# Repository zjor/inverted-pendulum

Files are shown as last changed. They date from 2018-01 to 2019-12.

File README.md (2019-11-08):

# Inverted Pendulum 

This repo contains simulations and numerical experiments related to my inverted pendulum robot hobby project

## Working project video

Inverted pendulum (https://www.youtube.com/watch?v=nOSTzpA0nGk)

## Articles
- [Все, что вы хотели знать об обратном маятнике](https://habr.com/ru/post/472588/)

## References
1. [Swing-up algorithm](https://pdfs.semanticscholar.org/47ef/ea6c73ef96ae933a378d4bf7ff3245a8584d.pdf)

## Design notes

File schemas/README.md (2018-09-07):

# Dimentions
For 2040 v-slot beam the distance between 23.89mm wheel centers is 60.4mm

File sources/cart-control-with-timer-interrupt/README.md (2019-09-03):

# Cart position control with timer interrupt

This code controls position of a cart with a stepper motor. Timer interrupt is used to control step delay precisely.

## Hardware
- DQ542MA stepper driver
- Arduino Uno
- Nema 17 stepper motor: 17HS4401

## Thoughts

Usage of interrupts allows logging system's state to console.
The problem arises when the motor should be driven very slowly, velocity update happens each step, e.i. each ISR call and if there is enough time between calls the system will evolve before the change is recognised and reflected in motion.

## References
- (http://maxembedded.com/2011/07/avr-timers-ctc-mode/)
- (https://www.instructables.com/id/Arduino-Timer-Interrupts/)

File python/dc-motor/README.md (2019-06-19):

# DC-motor simulations

## Equations of motion

### Electrical equation

U = L\frac{di}{dt} + Ri + kw

where 
- U - input voltage
- L - rotor inductance
- R - rotor coils resistance
- kw - back EMF term proportional to w

### Mechanical equation

J\frac{dw}{dt} + Bw = T_M - T_L = ki - mr^2\frac{dw}{dt}

where
- J - momentum of inertia of the rotor
- B - friction due to rotation
- T<sub>M</sub> - torque of the motor
- T<sub>L</sub> - torque of the load
- m - mass of the load
- r - radius of the shaft

Note that the friction due to the movement of the mass is neglected.

### Assumptions

\frac{L}{R} << \frac{J}{B}, => i = \frac{U}{R} - \frac{k}{Rw}

thus the DC-motor can be described with one equation

\frac{dw}{dt}(J + mr^2) + w(B + \frac{k^2}{R}) = \frac{kU}{R}

## The system to control

In this example I want to position a cart pulled by the motor at certain location, so that the system transitions from the state [x1, w1 (typically w1 = 0)] to [0, 0]

### Equations of the system

\begin{cases}\dot{x} = wr\\\dot{w}=-\alpha w + \beta U\end{cases}

where

\alpha = \frac{B + k^2/R}{J + mr^2} and 
\beta = \frac{k}{R(J + mr^2)}

### Controllability

A=\begin{bmatrix}0 & r\\ 0 & -\alpha\end{bmatrix}

B=\begin{bmatrix}0\\ \beta\end{bmatrix}

Controllability matrix 
\begin{bmatrix}B && AB\end{bmatrix} = \begin{bmatrix}0 && r\beta\\\beta && -\alpha\beta\end{bmatrix}
, rank equals 2 thus the system is controllable

## Step response
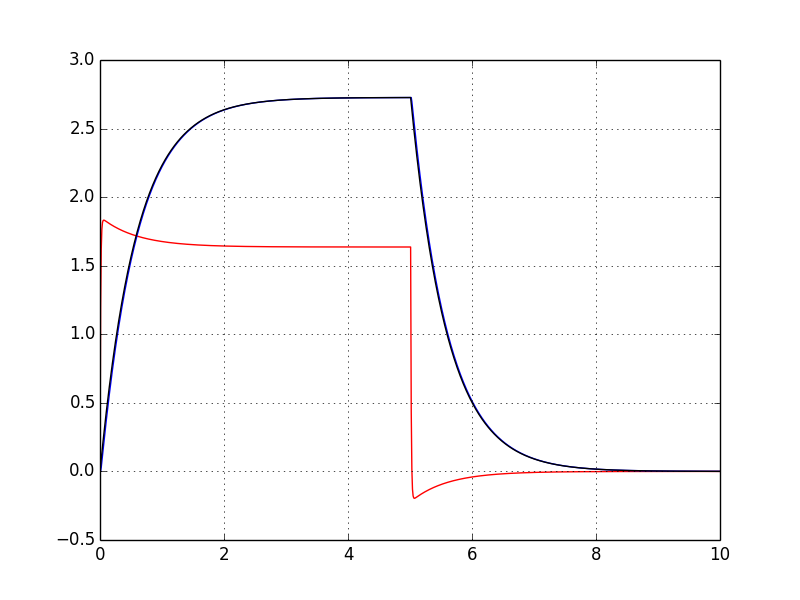
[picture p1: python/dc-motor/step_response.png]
Step Response


## PID controller
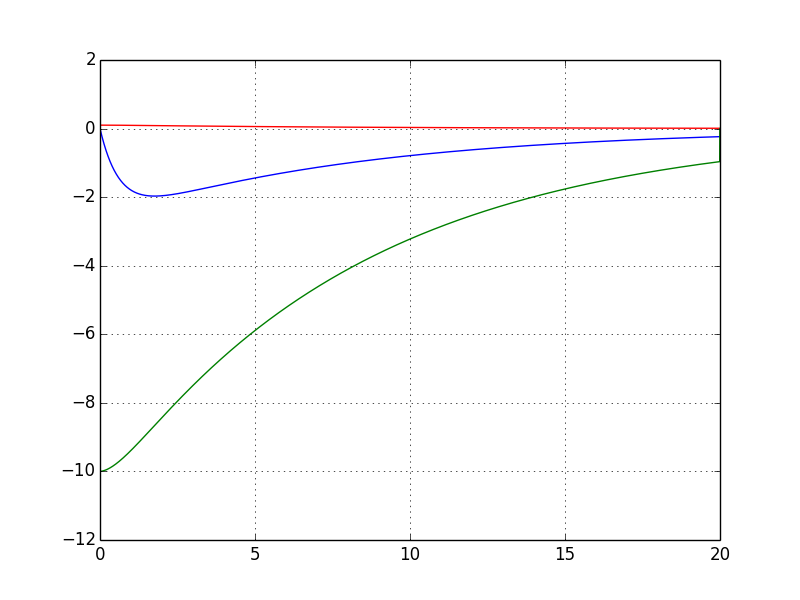
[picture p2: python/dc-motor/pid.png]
PID results


## LQR controller
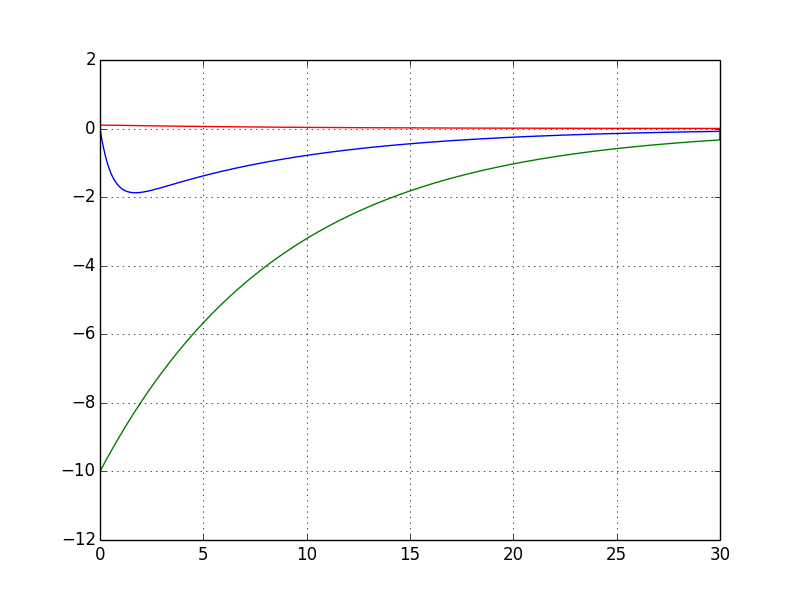
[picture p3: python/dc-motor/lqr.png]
LQR results


## TODO

- find alpha, beta parameters for the real motor based in step response
- take into account load friction and stall torque

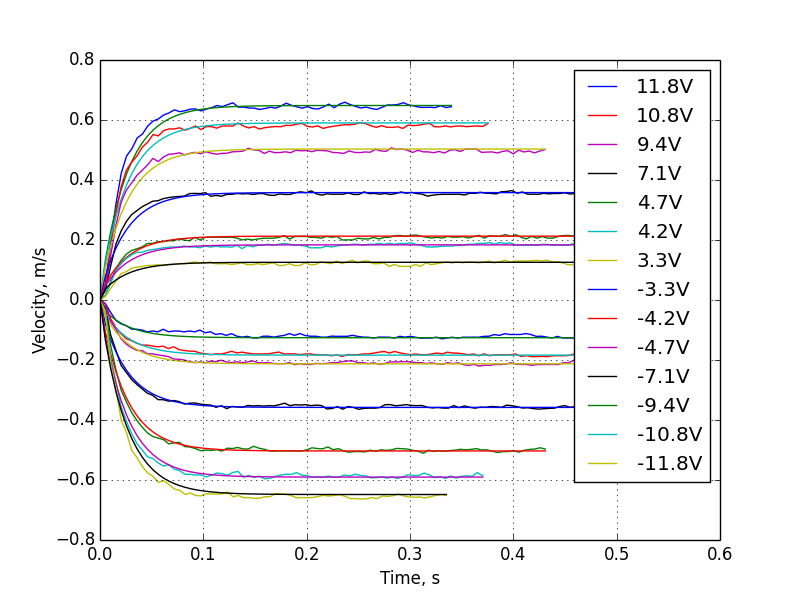
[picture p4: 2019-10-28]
dc-motor/params_fit.png

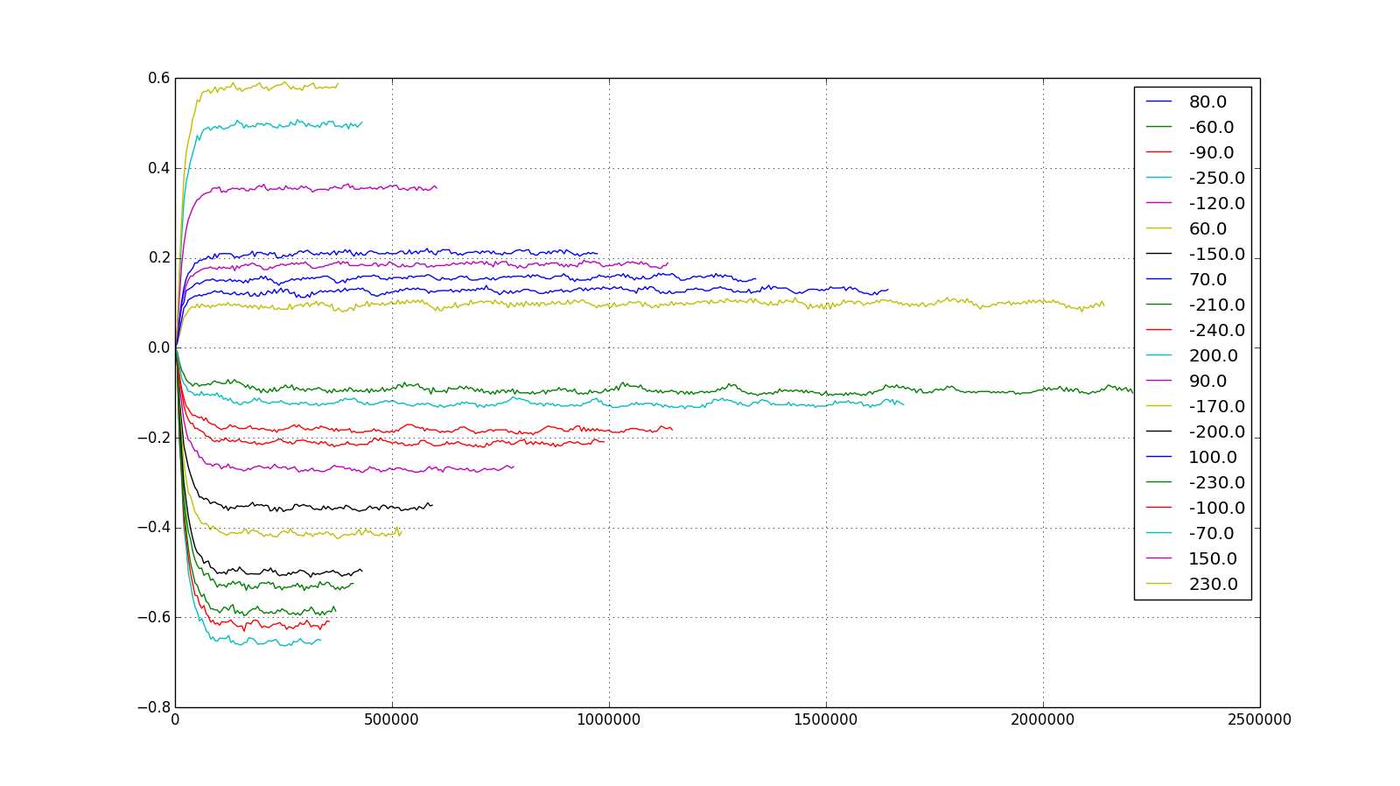
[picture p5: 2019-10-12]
dc-motor/velocity_per_pwm.png

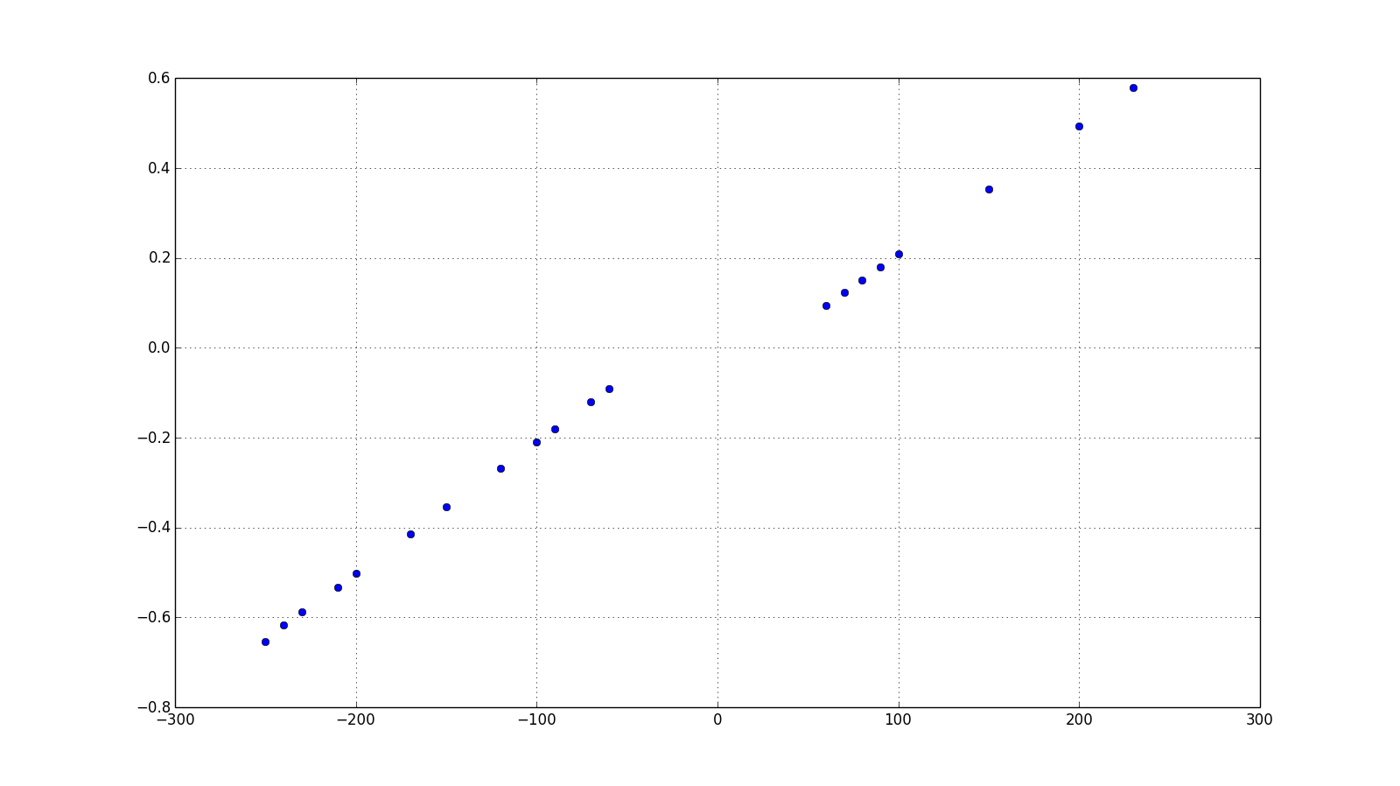
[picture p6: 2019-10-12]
dc-motor/set_velocity_per_pwm.png

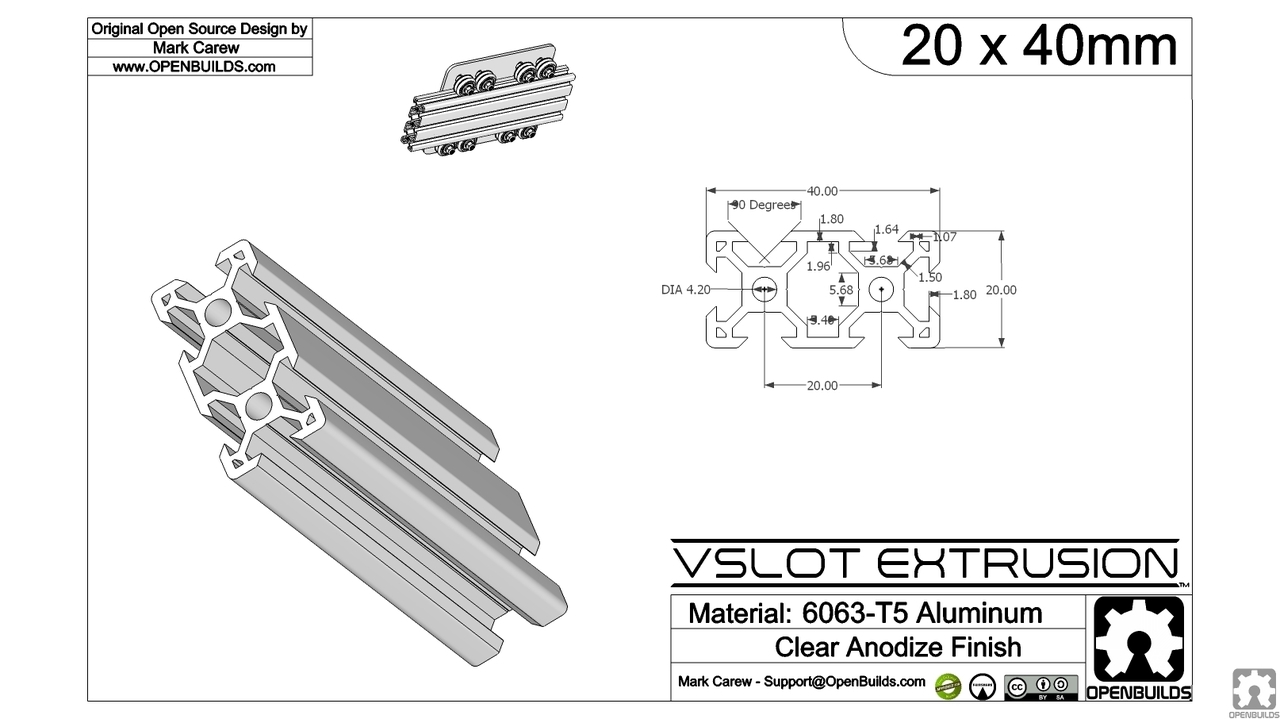
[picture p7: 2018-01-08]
schemas/v-slot_20x40.jpg

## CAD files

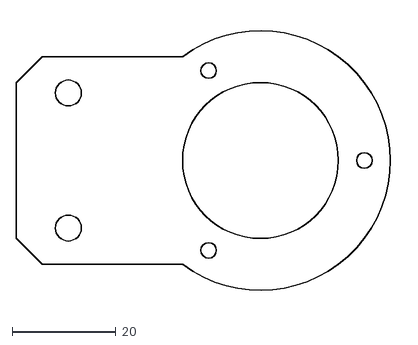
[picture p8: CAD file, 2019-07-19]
schemas/v2/encoder-holder.dxf
74.2 x 55.5

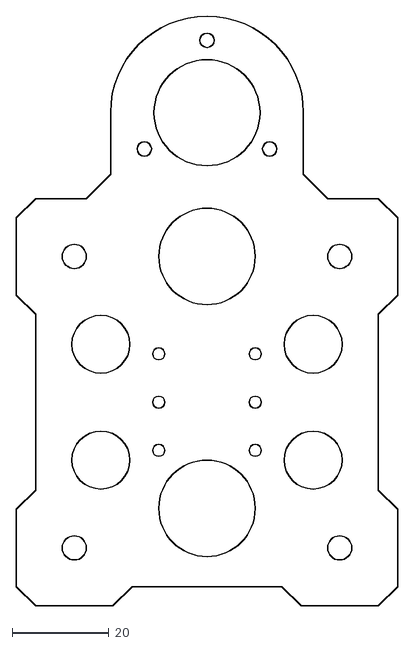
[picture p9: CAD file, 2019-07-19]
schemas/v2/cart-front.dxf
79.1 x 122.2

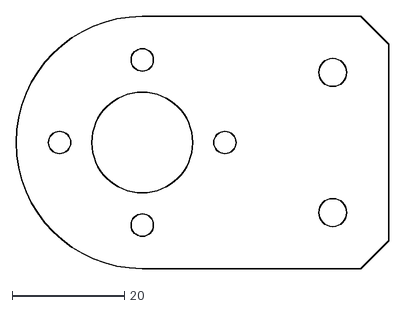
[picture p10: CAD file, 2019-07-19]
schemas/v2/motor-holder.dxf
66.5 x 45.0

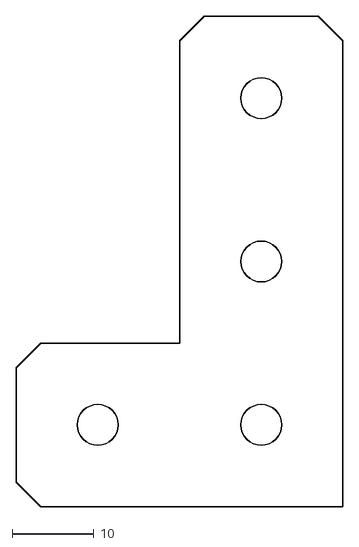
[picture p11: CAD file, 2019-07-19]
schemas/v2/beam-connector.dxf
40.0 x 60.0

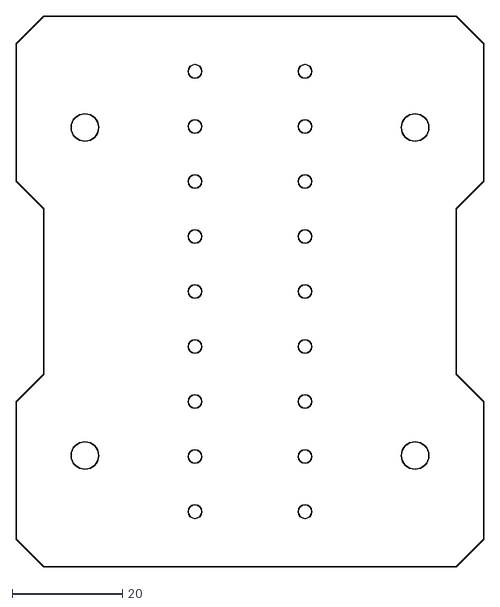
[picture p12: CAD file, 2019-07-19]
schemas/v2/cart-top.dxf
85.0 x 100.0

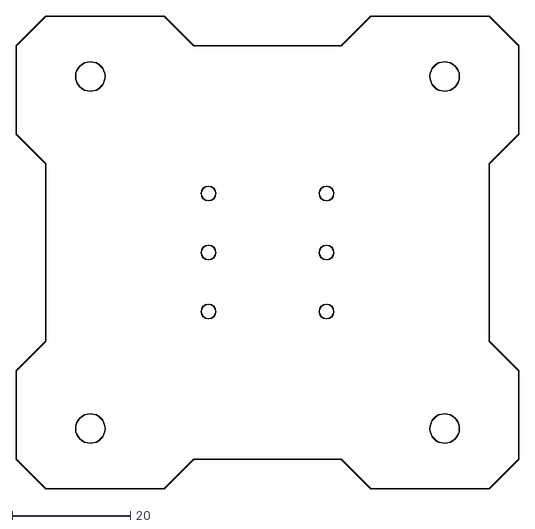
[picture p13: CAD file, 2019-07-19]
schemas/v2/cart-bottom.dxf
85.0 x 80.0

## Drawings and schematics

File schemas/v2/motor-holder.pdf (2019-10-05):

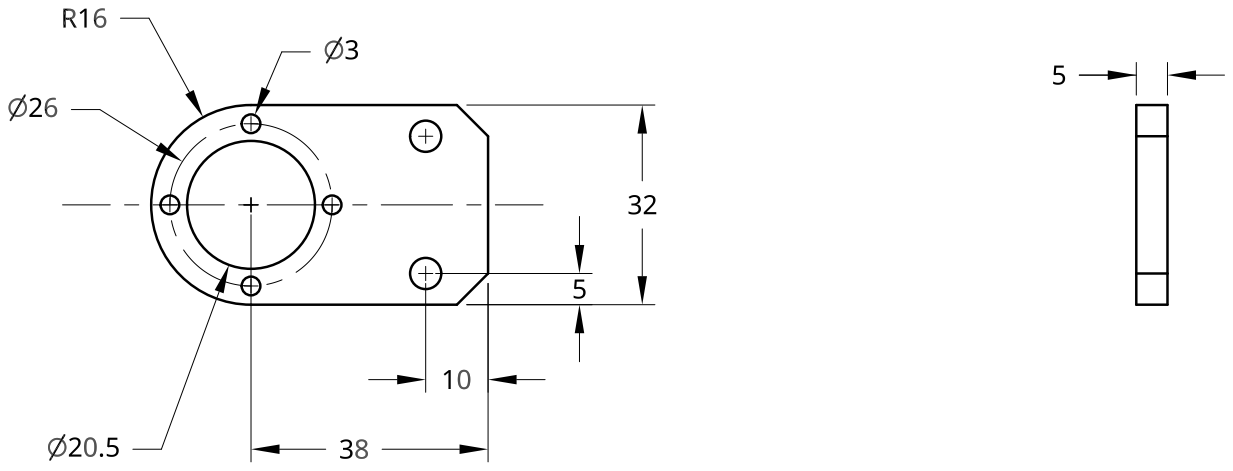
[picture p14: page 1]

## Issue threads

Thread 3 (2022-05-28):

estimate_params.py

yunjs24, 2022-05-28:
## inverted-pendulum/dc-motor/estimate_params.py ,  line 33

    when map obj converted into numpy array, it cannot express column size in data.shape

   so line 33
    with open(filename) as f:
        reader = csv.reader(f)
        for row in reader:
            data.append(map_to_float(row)) >> data.append(list(map(float, row)))

  tested in
  OS : wsl2 ubuntu in windows10
  pip 20.0.2 (python 3.8)

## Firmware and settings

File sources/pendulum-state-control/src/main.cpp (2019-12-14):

/**
 * == Inverted pendulum stabilisation with state control with DC motor ==
 * 
 * == Hardware specification ==
 * OMRON E6B2-CWZ6C pinout
 * - Brown - Vcc
 * - Black - Phase A
 * - White - Phase B
 * - Orange - Phaze Z
 * - Blue - GND
 *
 * LPD3806-600BM-G5-24C pinout
 * - Green - Phase A
 * - White - Phase B
 * - Red - Vcc
 * - Black - GND
 */

#include <Arduino.h>

// motor encoder pins
#define OUTPUT_A  3 // PE5
#define OUTPUT_B  2 // PE4

// pendulum encoder pins
#define REF_OUT_A 18 // PD3
#define REF_OUT_B 19 // PD2

// terminal switches pins
#define SWITCH_RIGHT  21
#define SWITCH_LEFT  20

// pulses per revolution
#define PPR  2400
#define SHAFT_R 0.00573
#define PENDULUM_ENCODER_PPR  10000

#define PWM_PIN 10
#define DIR_PIN 8

#define POSITION_LIMIT  0.145

#define STATE_CALIBRATE 0
#define STATE_SWING_UP  1
#define STATE_BALANCE   2
#define STATE_FULL_STOP 3
#define STATE_GO_RIGHT  4 
#define STATE_GO_LEFT   5
#define STATE_GO_CENTER 6

#define A 35.98
#define B 2.22
#define C 2.79

#define Kth 147.1
#define Kw  36.0
#define Kx  54.0
#define Kv  39.5

const float THETA_THRESHOLD = PI / 12;
const float PI2 = 2.0 * PI;

volatile long encoderValue = 0L;
volatile long lastEncoded = 0L;

volatile long refEncoderValue = 0;
volatile long lastRefEncoded = 0;

volatile boolean leftSwitchPressed = false;
volatile boolean rightSwitchPressed = false;

unsigned long now = 0L;
unsigned long lastTimeMicros = 0L;

// pulses count before the right switch pressed
long rightSwitchPulses;

float x, last_x, v, dt;
float theta, last_theta, w;
float control, u;

unsigned long log_prescaler = 0;

volatile bool debounce = false;
volatile long debounceTimestampMillis;

int state;

void encoderHandler();
void refEncoderHandler();

void leftSwitchHandler();
void rightSwitchHandler();

void calibrate();

void setup() {

  // setting PWD frequency on pin 10 to 31kHz
  TCCR2B = (TCCR2B & 0b11111000) | 0x01;

  pinMode(OUTPUT_A, INPUT_PULLUP);
  pinMode(OUTPUT_B, INPUT_PULLUP);

  pinMode(REF_OUT_A, INPUT_PULLUP);
  pinMode(REF_OUT_B, INPUT_PULLUP);

  pinMode(SWITCH_LEFT, INPUT);
  pinMode(SWITCH_RIGHT, INPUT);

  attachInterrupt(digitalPinToInterrupt(OUTPUT_A), encoderHandler, CHANGE);
  attachInterrupt(digitalPinToInterrupt(OUTPUT_B), encoderHandler, CHANGE);

  attachInterrupt(digitalPinToInterrupt(REF_OUT_A), refEncoderHandler, CHANGE);
  attachInterrupt(digitalPinToInterrupt(REF_OUT_B), refEncoderHandler, CHANGE);

  attachInterrupt(digitalPinToInterrupt(SWITCH_LEFT), leftSwitchHandler, FALLING);
  attachInterrupt(digitalPinToInterrupt(SWITCH_RIGHT), rightSwitchHandler, FALLING);


  pinMode(PWM_PIN, OUTPUT);
  pinMode(DIR_PIN, OUTPUT);

  digitalWrite(DIR_PIN, LOW);

  Serial.begin(9600);
  lastTimeMicros = 0L;
  state = STATE_CALIBRATE;
}

float saturate(float v, float maxValue) {
  if (fabs(v) > maxValue) {
    return (v > 0) ? maxValue : -maxValue;
  } else {
    return v;
  }
}

float getAngle(long pulses, long ppr) {  
  float angle = (PI + PI2 * pulses / ppr);
  while (angle > PI) {
    angle -= PI2;
  }
  while (angle < -PI) {
    angle += PI2;
  }
  return angle;
}

float getCartDistance(long pulses, long ppr) {
  return 2.0 * PI * pulses / PPR * SHAFT_R;
}

void driveMotor(float u) {
  digitalWrite(DIR_PIN, u > 0.0 ? LOW : HIGH);
  analogWrite(PWM_PIN, fabs(u));
}

boolean isControllable(float theta, float w, float x) {
  return fabs(theta) < THETA_THRESHOLD && fabs(w) < 0.5 && fabs(x) < 0.05;
}

void log_state(float control, float u) {
  if (fabs(w) > 100) {
    return;
  }

  if (state == STATE_FULL_STOP) {
    return;
  }

  // if (log_prescaler % 5 == 0) {
    Serial.print(state);Serial.print("\t");
    Serial.print(theta, 4);Serial.print("\t");
    Serial.print(w, 4);Serial.print("\t");
    Serial.print(x, 4);Serial.print("\t");
    Serial.print(v, 4);Serial.print("\t");
    Serial.print(control, 4);Serial.print("\t");
    Serial.println(u, 4);
  // }
  log_prescaler++;
}

float getBalancingControl(float x, float v, float theta, float w) {
  return Kx * x + Kv * v + Kth * theta + Kw * w;
}

float getSwingUpControl(float x, float v, float theta, float w) {
  float K = 10.0;
  float c = -copysignf(K, - w * cos(theta));
  float lim = 0.01;
  if ((x >= lim && c > 0) || (x <= -lim && c < 0) || fabs(theta) < PI / 2) {
    c = -(A * v + copysignf(C, v)); // causes to stop immediately
  }
  return c;
}

float integralError = 0.0;
float lastTarget = 0.0;
float getVelocityControl(float v, float target, float dt) {

  if (lastTarget != target) {
    lastTarget = target;
    integralError = 0.0;
  }

  float error = target - v;
  float Kp = 50.0;
  float Ki = 10.0;
  integralError += Ki * error * dt;
  return Kp * error + integralError;
}

float getPositionControl(float x, float v, float target) {
  float pKx = 60.0; //285.4;
  float pKv = 5.0; //37.1;
  return - (pKx * (x - target) + pKv * v);
}

void driveMotorWithControl(float control, float v) {
  u = (control + A * v + copysignf(C, v)) / B;
  u = 255.0 * u / 12.0;
  driveMotor(saturate(u, 254));
}

void loop() {

  if (millis() - debounceTimestampMillis > 100) {
    debounce = false;
  }

  if (leftSwitchPressed) {
    leftSwitchPressed = false;
    if (state == STATE_GO_LEFT) {
      Serial.println("The cart has reached the left end");
      long lengthPulses = rightSwitchPulses - encoderValue;
      encoderValue = -lengthPulses / 2;
      // float railLength = getCartDistance(lengthPulses, PPR);
      // Serial.print(lengthPulses); Serial.print("\t");
      // Serial.println(railLength);
      state = STATE_GO_CENTER;
    } else {
      state = STATE_FULL_STOP;
      Serial.println("[left] Unexpected state. Halt.");
    }
  }

  if (rightSwitchPressed) {
    rightSwitchPressed = false;
    rightSwitchPulses = encoderValue;
    Serial.println("The cart has reached the right end");
    if (state == STATE_GO_RIGHT) {
      state = STATE_GO_LEFT;
      Serial.println("Going left...");
    } else {
      state = STATE_FULL_STOP;
      Serial.println("[right] Unexpected state. Halt.");
    }    
  }

  now = micros();
  dt = 1.0 * (now - lastTimeMicros) / 1000000;
  x = getCartDistance(encoderValue, PPR);
  v = (x - last_x) / dt;

  theta = getAngle(refEncoderValue, PENDULUM_ENCODER_PPR);
  w = (theta - last_theta) / dt;

  if (fabs(x) >= POSITION_LIMIT && (state == STATE_BALANCE || state == STATE_SWING_UP)) {
    if (state != STATE_FULL_STOP) {
      Serial.println("Cart reached end of rail");
    }
    state = STATE_FULL_STOP;
  }

  switch (state) {
    case STATE_GO_RIGHT:
      control = getVelocityControl(v, 0.06, dt);
      driveMotorWithControl(control, v);
      break;
    case STATE_GO_LEFT:
      control = getVelocityControl(v, -0.06, dt);
      driveMotorWithControl(control, v);
      break;
    case STATE_CALIBRATE:
      Serial.println("Waiting for the pendulum to come to rest...");
      calibrate();
      Serial.println("Pendulum is at rest");
      state = STATE_GO_RIGHT;
      break;
    case STATE_GO_CENTER:
      if (isControllable(theta, w, x)) {
        state = STATE_BALANCE;
      } else if (fabs(x) < 0.01) {
        state = STATE_SWING_UP;
      } else {
        control = getPositionControl(x, v, 0.0);
        driveMotorWithControl(control, v);
      }
      break;
    case STATE_SWING_UP:
      if (isControllable(theta, w, x)) {
        state = STATE_BALANCE;
      } else {
        control = getSwingUpControl(x, v, theta, w);
        driveMotorWithControl(control, v);
      }
      break;
    case STATE_BALANCE:
      control = getBalancingControl(x, v, theta, w);
      driveMotorWithControl(control, v);
      break;
    case STATE_FULL_STOP:
      driveMotor(0);
      break;
  }
  
  last_x = x;
  last_theta = theta;
  lastTimeMicros = now;
      
  log_state(control, u);
  
  delay(5);
}

/**
 * Motor encoder handler
 */
void encoderHandler() {
  int MSB = (PINE & (1 << PE5)) >> PE5; //MSB = most significant bit
  int LSB = (PINE & (1 << PE4)) >> PE4; //LSB = least significant bit
  int encoded = (MSB << 1) | LSB; //converting the 2 pin value to single number
  int sum  = (lastEncoded << 2) | encoded; //adding it to the previous encoded value

  if(sum == 0b1101 || sum == 0b0100 || sum == 0b0010 || sum == 0b1011) {
    encoderValue++; //CW
  }
  if(sum == 0b1110 || sum == 0b0111 || sum == 0b0001 || sum == 0b1000) {
    encoderValue--; //CCW
  }

  lastEncoded = encoded; //store this value for next time  
}

/**
 * Pendulum encoder handler
 * Encoder attached to pins:
 * Phase A - 18 PD3
 * Phase B - 19 PD2
 */
void refEncoderHandler() {
  int MSB = (PIND & (1 << PD3)) >> PD3; //MSB = most significant bit
  int LSB = (PIND & (1 << PD2)) >> PD2; //LSB = least significant bit
  int encoded = (MSB << 1) | LSB; //converting the 2 pin value to single number
  int sum  = (lastRefEncoded << 2) | encoded; //adding it to the previous encoded value

  if(sum == 0b1101 || sum == 0b0100 || sum == 0b0010 || sum == 0b1011) {
    refEncoderValue++; //CW
  }
  if(sum == 0b1110 || sum == 0b0111 || sum == 0b0001 || sum == 0b1000) {
    refEncoderValue--; //CCW
  }

  lastRefEncoded = encoded; //store this value for next time  
}

/**
 * Waits till pendulum stays at rest in the vertical position
 */
void calibrate() {
  long lastReading;
  do {
    lastReading = refEncoderValue;
    delay(1000);
  } while (lastReading != refEncoderValue);
  cli();
  refEncoderValue = 0;
  sei();
}

void leftSwitchHandler() {  
  leftSwitchPressed = true && !debounce;
  debounce = true;
  debounceTimestampMillis = millis();
}

void rightSwitchHandler() {
  rightSwitchPressed = true && !debounce;
  debounce = true;
  debounceTimestampMillis = millis();
}

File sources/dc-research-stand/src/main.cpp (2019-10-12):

/**
 * == DC motor research stand ==
 * 
 * This software is used to collect data on DC motor acceleration profile in order to estimate
 * motor's constants for further usage in control applications.
 * 
 * == Hardware specification ==
 * OMRON E6B2-CWZ6C pinout
 * - Brown - Vcc
 * - Black - Phase A
 * - White - Phase B
 * - Orange - Phaze Z
 * - Blue - GND
 *
 * LPD3806-600BM-G5-24C pinout
 * - Green - Phase A
 * - White - Phase B
 * - Red - Vcc
 * - Black - GND
 */

#include <Arduino.h>

#include "PID.h"

// motor encoder pins
#define OUTPUT_A  3 // PE5
#define OUTPUT_B  2 // PE4

// pulses per revolution
#define PPR  2400
#define SHAFT_R 0.00573

#define PWM_PIN 10
#define DIR_PIN 8

#define MAX_STALL_U 30.0
#define POSITION_LIMIT  0.2

#define Kp  10000.0
#define Kd  600.0
#define Ki  2000.0

#define STATE_PENDING_COMMAND 0
#define STATE_RUNNING         1
#define STATE_HOMING          2

#define DATA_BUF_SIZE 500

volatile long encoderValue = 0L;
volatile long lastEncoded = 0L;
long startEncoderValue = 0L;

unsigned long lastTimeMillis = 0L;
unsigned long startTimeMicros = 0L;

unsigned long times[DATA_BUF_SIZE];
unsigned long values[DATA_BUF_SIZE];
int index = 0;


float amp = 255;
float u = 0.0;
float w = 0.0;
float dt = 0.0;

float x, last_x;

unsigned int state = STATE_PENDING_COMMAND;

char buf[8];
int buf_pos = 0;
int pwm = 0;

PID cartPID(Kp, Kd, Ki, 0.);

void encoderHandler();

void setup() {

  // setting PWD frequency on pin 10 to 31kHz
  TCCR2B = (TCCR2B & 0b11111000) | 0x01;

  pinMode(OUTPUT_A, INPUT_PULLUP);
  pinMode(OUTPUT_B, INPUT_PULLUP);

  attachInterrupt(digitalPinToInterrupt(OUTPUT_A), encoderHandler, CHANGE);
  attachInterrupt(digitalPinToInterrupt(OUTPUT_B), encoderHandler, CHANGE);

  pinMode(PWM_PIN, OUTPUT);
  pinMode(DIR_PIN, OUTPUT);

  digitalWrite(DIR_PIN, LOW);

  Serial.begin(9600);
  Serial.println("Enter PWM");
  lastTimeMillis = 0L;
}

float avoidStall(float u) {
  if (fabs(u) < MAX_STALL_U) {
    return u > 0 ? u + MAX_STALL_U : u - MAX_STALL_U;
  }
  return u;
}

float saturate(float v, float maxValue) {
  if (fabs(v) > maxValue) {
    return (v > 0) ? maxValue : -maxValue;
  } else {
    return v;
  }
}

float getCartDistance(long pulses, long ppr) {
  return 2.0 * PI * pulses / PPR * SHAFT_R;
}

void clear_buf(char *buf, int len) {
    int i = 0;
    while (i < len) {
        buf[i++] = 0;
    }
}

void driveMotor(float u) {
  digitalWrite(DIR_PIN, u > 0.0 ? LOW : HIGH);
  analogWrite(PWM_PIN, fabs(u));
}

void startMeasurements(int pwm) {
  Serial.print("\nRunning at PWM: "); Serial.println(pwm);
  index = 0;
  startTimeMicros = micros();
  startEncoderValue = encoderValue;
  
  state = STATE_RUNNING;

  driveMotor(pwm);    
}

void loop() {    
    x = getCartDistance(encoderValue, PPR);

    if (state == STATE_PENDING_COMMAND) {
        if (Serial.available() > 0) {
            int c = Serial.read();
            if ((isDigit(c) || c == '-') && buf_pos < 8) {
                buf[buf_pos++] = (char)c;
                Serial.print((char)c);
            } else if (c == '\n') {
                pwm = atoi(buf);
                buf_pos = 0;
                clear_buf(buf, 8);
                startMeasurements(pwm);
            }
        }
    } else if (state == STATE_RUNNING) {
        unsigned long nowMicros = micros();
        unsigned long ticks = nowMicros - startTimeMicros;
        long measurement = encoderValue - startEncoderValue;

        times[index] = ticks;
        values[index] = measurement;
        index++;

        if (fabs(x) > POSITION_LIMIT || ticks > 5000000 || index > DATA_BUF_SIZE) {
            driveMotor(0);
            
            for (int i = 0; i < index; i++) {
              Serial.print(i);Serial.print(",");
              Serial.print(pwm);Serial.print(",");
              Serial.print(times[i]);Serial.print(",");
              Serial.println(getCartDistance(values[i], PPR), 6);
            }

            state = STATE_HOMING;
            Serial.println("Homing...");
        }
        delay(5);
    } else if (state == STATE_HOMING) {
        if (fabs(x) <= 0.005) {
          driveMotor(0);
          state = STATE_PENDING_COMMAND;
          Serial.println("Homing complete\nEnter PWM");
          return;
        }
        unsigned long now = millis();
        dt = 1.0 * (now - lastTimeMillis) / 1000.0;
        lastTimeMillis = now;
        u = cartPID.getControl(x, last_x, dt);
        driveMotor(saturate(avoidStall(u), 240));
        delay(5);
    }
    
    last_x = x;    
}

void encoderHandler() {
  int MSB = (PINE & (1 << PE5)) >> PE5; //MSB = most significant bit
  int LSB = (PINE & (1 << PE4)) >> PE4; //LSB = least significant bit
  int encoded = (MSB << 1) | LSB; //converting the 2 pin value to single number
  int sum  = (lastEncoded << 2) | encoded; //adding it to the previous encoded value

  if(sum == 0b1101 || sum == 0b0100 || sum == 0b0010 || sum == 0b1011) {
    encoderValue++; //CW
  }
  if(sum == 0b1110 || sum == 0b0111 || sum == 0b0001 || sum == 0b1000) {
    encoderValue--; //CCW
  }

  lastEncoded = encoded; //store this value for next time  
}

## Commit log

2017-09-21 free mount simulation
2017-10-21 stabilize with PID
2018-01-08 moving plate v1
2018-03-17 current state
2018-07-08 testing weird regulator
2018-10-16 low-pass filter example added
2018-10-17 regulator updates
2018-11-03 reading angle via interrupts
2019-03-02 stabilising short new construction
    [pd-regulator.ino]
2019-03-02 reading adc by interrupt directly
2019-03-02 current status
2019-03-15 kalman filter
2019-04-24 position control with threading
2019-04-24 encoder test script
2019-04-25 encoder & plotting
2019-04-25 encoder data norm
2019-06-18 dc-motor sims added
2019-06-18 lqr controller for DC motor
2019-06-18 DC cart control with pid
2019-06-25 dc-motor control: wip
2019-06-28 DC motor simulation with LQR
2019-07-19 drawings and calibrarion
    [beam-connector.dxf, cart-bottom.dxf, cart-front.dxf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]
2019-08-09 cart positioning with stepper controller
2019-08-09 ip with incremental encoder sketch was added
2019-08-09 encoder handler
2019-09-03 replaced encoder
2019-09-05 PID velocity control of DC motor
2019-09-05 PID position control
2019-09-19 pendulum: pure PID: wip
2019-09-22 DC-motor simulation using library
2019-09-22 pendulum pid with library
2019-10-02 dc motor position pid with atmega2560
2019-10-02 wiring another encoder
2019-10-02 set ref by encoder
2019-10-05 quiet PWM
2019-10-06 tuning PID params
2019-10-07 params estimation: init
    [dc-params-pwm-100.csv, dc-params-pwm-110.csv, dc-params-pwm-120.csv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]
2019-10-08 plotting data
    [dc-params-pwm-150.csv, dc-params-pwm-240.csv, dc-params-pwm-50.csv]
2019-10-11 dc-params measurements app
    [dc-params-pwm-100.csv, dc-params-pwm-110.csv, dc-params-pwm-120.csv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]
2019-10-11 time in micros & distance in meters
    [pwm-100.csv, pwm-150.csv, pwm-200.csv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]
2019-10-12 more data
    [pwm-110.csv, pwm-120.csv, pwm-170.csv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]
2019-10-12 negative voltage data
    [pwm-rev-100.csv, pwm-rev-120.csv, pwm-rev-150.csv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]
2019-10-12 plotting set velocity
2019-10-12 dc motor state control
2019-10-13 dc motor control with LQR
2019-11-08 make sound with PWM
2019-12-05 terminal switches added
2019-12-05 steady movement to the rail endings
2019-12-14 device swing-up
2020-11-27 torque control: wip
2020-12-07 motor simulation: wip
2020-12-09 current control
2020-12-10 velocity control
